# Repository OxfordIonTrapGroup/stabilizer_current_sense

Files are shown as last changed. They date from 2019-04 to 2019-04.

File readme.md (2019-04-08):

Analogue front-end mezzanine for [Stabilizer](https://github.com/sinara-hw/stabilizer), providing current sense (with reference subtraction) and modulation (feedback + feedforward). Originally designed to reduce magnetic field noise in AMO physics experiments. See [Merkel et al.](https://arxiv.org/abs/1808.03310) for details.

Pre-build schematics, gerbers etc are avaliable in the [releases](https://github.com/OxfordIonTrapGroup/stabilizer_current_sense/releases) section. [sim.ipynb](https://github.com/OxfordIonTrapGroup/stabilizer_current_sense/blob/master/sim.ipynb) contains design notes, noise simulations, etc

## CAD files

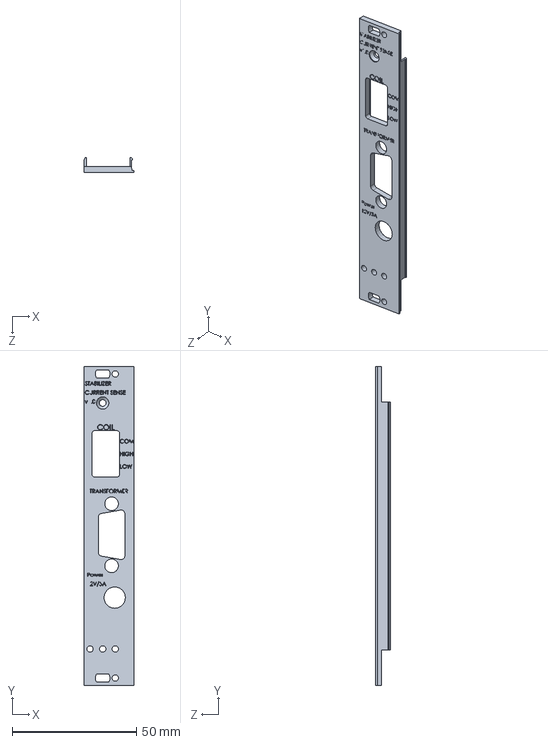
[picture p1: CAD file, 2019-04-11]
panel/panel.SLDPRT
20.0 x 128.4 x 6.20 mm

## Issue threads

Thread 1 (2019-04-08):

board-board connector heights

hartytp, 2019-04-08:
The -33 connectors are too long given the male connectors used in Stabilizer. The -23 connectors I've used look a bit marginal. See the STEP exports for a clearer picture.

Consider adding a spacer to increase the contact area between the male connectors on Stabilizer and the female ones on the AFE?

hartytp, 2019-04-08:
Well, probably not a spacer but rather a note that the AFE connectors should be soldered approx 1mm away from the PCB to increase the length.

hartytp, 2019-04-08:
Looking at the connector models more closely I think this will be fine; the connectors are sprung so that contact is only at the tips so not much insertion should be needed for proper contact. Still to be safe I’ll leave the connectors off the initial BOM and solder them be hand once I’ve test-fitted.

Closed 2019-04-12.

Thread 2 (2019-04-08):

1v.0 rc1 design review

hartytp, 2019-04-08:
@gkasprow I've just posted a first version of the design, would you mind taking a look?

The only obvious issue I see is #1

Note that I've put quite a lot of thought into the grounding, since we need to measure <1uV voltages across the sense resistor. In a previous version we had some nasty issues like: an LED that flashed at ~1Hz and we could see a corresponding signal on the current measurement; the current sunk by the shunts created a ground voltage that altered the current measurement. These were all fixed with grounding, but it took some care!

Other than that, it would be great if you could have a look at the usuals (schematic, layout, mechanics) and, since I'm new to Altium, do let me know if you see anything silly with the way I've set the Altium project up.

Otherwise, I'll order some of these boards in the next few days. Is one enough for you?

hartytp, 2019-04-09:
Now on rc2.

Main change is that when I added a mating connector for the terminal block I noticed that the locking terminal blocks wouldn't fit. Fixed the component placements and panels to allow use of locking terminal blocks.

NB we won't be able to use one of the fancy Schroff panels with EMC gaskets unless we trim the pins on the terminal block. But, the same goes for the SMAs on Stabilizer AFAICT.

Other than that, the mechanics looks good apart from #1.

gkasprow, 2019-04-10:
@hartytp
- trimming pins is the usual procedure.
- there are missing decoupling caps on IC11 and IC10 supplies
- move all 3D models to layer 13
- missing board outline on mechanical 1. This is needed for PCB milling.
- mask vias, don't treat them as test points because can be easily damaged with a probe

gkasprow, 2019-04-10:
edit, the decoupling caps are there, on other sheet :)

gkasprow, 2019-04-10:
What is D1 for? Wouldn't it be better to use it in the feedback loop to close it for negative inputs?

hartytp, 2019-04-10:
> trimming pins is the usual procedure

ack. Is that something that you specify somewhere on the PCB? Or just leave to the assembly house to figure out?

> there are missing decoupling caps on IC11 and IC10 supplies
> edit, the decoupling caps are there, on other sheet :)

Nope, they're there on the same sheet. C34-C36

> move all 3D models to layer 13

Done

> missing board outline on mechanical 1. This is needed for PCB milling.

Okay, I'll add that.

> mask vias, don't treat them as test points because can be easily damaged with a probe

Done. Thanks

hartytp, 2019-04-10:
> What is D1 for? Wouldn't it be better to use it in the feedback loop to close it for negative inputs?

May not be necessary. The idea is to protect the transitor's base from negative voltages when the feedback loop rails low.

gkasprow, 2019-04-10:
the air flow cooling the output transistors can be blocked by the DC/DC converter. I don't know how hot they are going to be.
Trimming of the pins will be done during panel assembly so the assembly house will figure it out

hartytp, 2019-04-10:
> the air flow cooling the output transistors can be blocked by the DC/DC converter. I don't know how hot they are going to be.

Imax is about 0.1A. The power depends on the coil voltage. Assume a max coil voltage of something like 10V (which is pretty high) the max power will be 1 W. The [heatsink](https://www.fischerelektronik.de/web_fischer/en_GB/heatsinks/C02/Attachable%20heatsink/PG/FK242SA220O/search.xhtml) specifies 26K/W thermal resistance, but not sure what air flow that assumes. Either way, the transistors shouldn't get too hot, maybe 50C or so.

I'm assuming we'll mount the circuit virtically in an enclosure with some vent holes on the top.

gkasprow, 2019-04-10:
When making cuts via power planes, make sure they are not shorted on other layers for AC.
At the moment the cutout is shorted by R50. The N15 plane is also placed across the cutout.

gkasprow, 2019-04-10:
the EMI filter should be placed as close to the connector as possible. When placed somewhere else its effectiveness gets degraded, especially for higher frequencies. it would fit nicely on the bottom side, close to the connector.

gkasprow, 2019-04-10:
watch the via sizes on power rails. I add a dedicated rule and make sure all power rails are added to the power class.
Use two or three vias in parallel. If Altium is removing them, add piece of copper fill to connect them together (p-f command). At the moment the pin 1 of EMI filter is connected  to the power connector witn big via which has 0.5mm hole

gkasprow, 2019-04-10:
Wouldn't make it better to place RN1 on the bottom side? The feedback traces seem to be quite long.
I don't care on signal integrity but interference pickup.

gkasprow, 2019-04-10:
Good idea with adding panels to the BOM!

gkasprow, 2019-04-10:
are you sure the connectors you used are good for such stacking? On the 3D view it looks like the header may have too short pins to ensure reliable contact. It depends on how the receptacles are built - if they have an active contact surface close to the pin entry or at some depth.

hartytp, 2019-04-10:
Thanks Greg. Let me know when you've finished your review.

gkasprow, 2019-04-10:
I didn't found any other issues.

hartytp, 2019-04-10:
Thanks @gkasprow!

hartytp, 2019-04-10:
> move all 3D models to layer 13

So, here you mean J7 as well as the screws, washers and stand-offs, right? I think everything else was already on the correct layer.

For stand-off/alignment purposes, is mechanical 1 the same as top layer?

hartytp, 2019-04-10:
> missing board outline on mechanical 1. This is needed for PCB milling.

@gkasprow is there an easy way to have altium copy the board outline on to m1 or do I need to manually trace it using zero-thickness lines?

hartytp, 2019-04-10:
> When making cuts via power planes, make sure they are not shorted on other layers for AC.
At the moment the cutout is shorted by R50.

R50 and other similar resistors are DNP by default. They are deliberately placed there to short across the isolation gap if we decide we want to tie all grounds together at some point. There is a schematic annotation about this.

> The N15 plane is also placed across the cutout.

Several power planes cut across the isolation gap. But, this is a requirement to bring the signals out. I don't think we can avoid it. I wasn't expecting this to be a problem, as the capacitance between the layers should be relatively small and the noise frequencies should be relatively low. Do you think this is really likely to be an issue? How would you alter the layout to improve it?

> the EMI filter should be placed as close to the connector as possible. When placed somewhere else its effectiveness gets degraded, especially for higher frequencies. it would fit nicely on the bottom side, close to the connector.

I did think about doing that. However, in this particular case, I deliberately chose not to do that. The reason is that the area near the barrel connector has my low-noise AFE ground, so I do not want to ground the CMC there. I want to ground the CMC in the "noisy" region near the main SMPS.

I know this will degrade the CMC performance somewhat for high frequenices, but my assumption was that the bulk of the noise we want to filter out is <1MHz so the coupling between the power input traces and the surrounding ground planes should be very small.

What do you think?

> watch the via sizes on power rails. I add a dedicated rule and make sure all power rails are added to the power class.
Use two or three vias in parallel. If Altium is removing them, add piece of copper fill to connect them together (p-f command). At the moment the pin 1 of EMI filter is connected to the power connector witn big via which has 0.5mm hole

> Wouldn't make it better to place RN1 on the bottom side? The feedback traces seem to be quite long.
I don't care on signal integrity but interference pickup.

Yes, I guess we can do that. I'm used to hand soldering PCBs so I like to keep all components on one side where possible :) It's also nice to keep all components on the same layer in case we want to add a screening around the low noise parts can or something later on. Also, the layout currently puts keeps all critical ground connections (the reference, the dividers, the DAC and the feedback resistors) very close together, which seemed nice.

In any case, the feedback traces are not so long (~15mm) and the subsequent stages have filtering.

So, all in all, I hoped the current layout would be fine. What do you think?

> Are you sure the connectors you used are good for such stacking? On the 3D view it looks like the header may have too short pins to ensure reliable contact. It depends on how the receptacles are built - if they have an active contact surface close to the pin entry or at some depth.

Yes...this is https://github.com/OxfordIonTrapGroup/stabilizer_current_sense/issues/1 I think it may be an issue.

Let's discuss the problem in that thread. Briefly though:
- there is no connector that I could find which is a closer match for our stack up. The longer connectors are about 1mm too long to mate with the headers on Stabilizer.
- one possibility would be to solder the connectors slightly below the AFE PCB to increase the mating lenght. e.g. we can solder them in situ with the board mounted on Stabilizer, or we can add a 1mm spacer before soldering.
- From the connector models in the step file, it looks like the female connectors are sprun-loaded with a contact point right at the tip, so this may not be an issue in the end. But, it's hard to be confident until we play with the hw...

gkasprow, 2019-04-10:
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

OK
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

I would simply make some supply rails longer that go around the slot. Look how it was made on Sampler.

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

you can ground it in another place. At the moment the input traces are capacitively coupled with your AFE ground.

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

probably does not really mater at such low frequencies we are working.

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

that is fine, I'm talking only on general engineering rules :)

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

this needs to be communicated to the assembly house. They will use standoffs to mount the connector in elevated way.

>     From the connector models in the step file, it looks like the female connectors are sprun-loaded with a contact point right at the tip, so this may not be an issue in the end. But, it's hard to be confident until we play with the hw...
>

this should not be an issue then.

hartytp, 2019-04-11:
@gkasprow for power planes, what via hole and annuls size do you recommend? How many in parallel for a few hundred mA?

gkasprow, 2019-04-11:
0.4/0.7mm, 2 in parallel.

Closed 2019-04-11.

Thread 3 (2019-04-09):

box

cjbe, 2019-04-09:
@gkasprow can you recommend any compact stand-alone cases which we could mount Stabilizer + mezzanine in using standard Schroff FPs?

gkasprow, 2019-04-10:
U can use [these](https://www.parkfield.co.uk/verotec_us/lbx-tac-print.jpg) or [these](http://www.farnell.com/datasheets/48895.pdf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)
The later one I have in my lab.

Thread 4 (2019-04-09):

box grounding

hartytp, 2019-04-09:
I'll make a final decision on this later on and then add some notes/alter population options in the schematic. But, my provisional grounding plan is:
1. We float the stabilizer front panel so that it connects electrically to the box but not to stabilizer
2. We connect the AFE panel to the AFE board in exactly 1 place using the DNPd resistor right by the main star ground point
3. We connect the AFE panel to the chassis electrically
4. We tie either COIL_COMMON or the chassis to the optics table

That way we get a nice star ground with no loops...

hartytp, 2019-04-11:
Here is what we will do:
1. Stabilizer connects its circuit ground to the panel ground in several places (can't avoid that)
2. Connect both stabilizer and AFE grounds to the chassis (e.g. star washers on case)
3. Then either ground the chassis, or ground coil common

Closed 2019-04-11.

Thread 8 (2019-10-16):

v1.0 testing

hartytp, 2019-10-16:
- [ ] measure all voltage rails and check within spec. Check with scope that nothing oscillating etc
- [ ] program SPI AFE DAC and verify output
- [ ] short current input and measure noise spectrum (if we can't do this because of offsets, we can use a battery + precision resistor to produce a small bias current with very low noise)
- [ ] Compare noise measurements to simulations in notebook
- [ ] Get stabilizer CPU DAC working to bias current shunts
- [ ] test current shunts by hooking up to external current source and putting a square-wave on the stabilizer SPI DAC. Look at sense resistor on scope to measure step response
- [ ] try running closed-loop

pathfinder49, 2019-10-16:
| V Rail    | Voltage (DMM) |
|------------|---------------------|
| P15V0   | 15.12 V |
| N15V0   | -14.96 V |
| P12V0A | 12.01 V |
| N12V0A | -12.05 V |
| 12V0AS | 12.29 V |
| VREF    | 2.500 V |
| P5V0    | 4.971 V |

Verified on a scope that the rails aren't oscillating.

hartytp, 2019-10-16:
Are those all within spec for the PCB?

pathfinder49, 2019-10-16:
>
>
> Are those all within spec for the PCB?

Those are all within spec of the connected components. I can't seem to find a tolerance within the PDF.

hartytp, 2019-10-16:
> Those are all within spec of the connected components

That's all I meant; cast an eye over the PCB, dig out the ICs and see what accuracy you expect from that.

pathfinder49, 2019-10-28:
Below are the stabilizer ADC readings when connected to stabilizer_current_sense. (I've plotted every 100th point)

`np.diff(data).std()/2**.5` = 10.8 LSB or 1.3 mV

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

pathfinder49, 2019-10-28:
With R33 and R34 populated and Coil COM and Coil LOW shorted.

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

There is a significant voltage offset with this configuration. See [new issue](https://github.com/OxfordIonTrapGroup/stabilizer_current_sense/issues/9).

pathfinder49, 2019-10-28:
The voltage fluctuations appear to originate from a [broken capacitor in the DAC filter](https://github.com/OxfordIonTrapGroup/stabilizer_current_sense/issues/10).

Using a different current_sense_board:
`np.diff(data).std()/2**.5` = 10.8 LSB or 1.3 mV (no significant change to previous board)
(6.2 mV RMS noise on scope)
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

hartytp, 2019-10-28:
@pathfinder49 can you fft that to extract the nsd and compare it to the simulation please? Looks about right but would be nice to see the nsd plot

hartytp, 2019-10-28:
@pathfinder49 are you saying the ADC reads 1.3mVrms but the scope gives 6.4?

pathfinder49, 2019-10-28:
Yes, I'll double check my conversion once I've eaten. Might have /2 instead of x2...

pathfinder49, 2019-10-28:
I believe my conversion is correct. The `np.diff(data).std()/2**.5` disagrees with the rms of the ADC data (2.4 mV). However, this RMS also disagrees with the scope...

Below is the NSD of the ADC data (assuming 1 MHz sampling TBC):
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

hartytp, 2019-10-28:
I'm confused. Why are you differentiating the data?

hartytp, 2019-10-28:
Where does `np.diff(data).std()/2**.5` come from? Don't just just want `np.std`?

hartytp, 2019-10-28:
Pretty sure sampler currently samples at 500kHz (try injecting a 1kHz sinusoid from an AWG to confirm).

pathfinder49, 2019-10-28:
For a comparison of the no capacitor related noise

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

hartytp, 2019-10-28:
> For a comparison of the no capacitor related noise

Okay...but I don't get where that formula came from in the first place...

hartytp, 2019-10-28:
nit: always use grids for that kind of plot, and may be best to give y scale as a log (dBV/sqrt(Hz))

hartytp, 2019-10-28:
- did you add a 10nF capacitor in place of the 10uF yet? Or is this all no capacitor?
- is the NSD you're plotting there RTI (i.e. divided by the gain)?

hartytp, 2019-10-28:
I don't understand the data on the plot. AFAICT it says 1uV/rtHz for 500kHz BW. That would be 1.4nV/rtHz. Even if that's RTI it's non-physically low (1kOhm is 4nV/rtHz at room temperature and we have a bunch of 1k resistors. Check the noise model, but I'd guess the AFE noise floor is closer to 10nV/rtHz). So, check it in the AM, but I don't trust your data yet...

dnadlinger, 2019-10-28:
> I don't understand the data on the plot. AFAICT it says 1uV/rtHz for 500kHz BW.

Wait what? 1 µV / rtHz is 1 µV / rtHz no matter the bandwidth. For, order-of-magnitude 500 kHz noise bandwidth, this gives 0.7 mV rms, so factors of 2 might be wrong, but not factors of 1000.

hartytp, 2019-10-28:
@dnadlinger indeed...it’s late and my brain clearly no longer functions!

hartytp, 2019-10-28:
Still though 1uV/rtHz would be 0.5nVrtHz before gain of 2k, so still at least an order of magnitude too low.

pathfinder49, 2019-10-29:
It was suggested in the stabilizer characterisation

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

pathfinder49, 2019-10-29:
Working through the circuit diagram, I hadn't accounted for the op amp dividing input voltage by 5.

I've updated the nsd and voltage above.

hartytp, 2019-10-29:
> Working through the circuit diagram, I hadn't accounted for the op amp dividing input voltage by 5.

So, the calculation you need is that 2^16 is 20V at the input to Stabilizer (the header/SMA).

pathfinder49, 2019-10-29:
Here is the nsd after savgol filtering
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

Overall the NSD is better than expected from the noise calculation. [This may have to do with the bandwidth.](https://github.com/OxfordIonTrapGroup/stabilizer_current_sense/issues/12)

hartytp, 2019-10-29:
Thanks!

Assuming the spice model is correct, the 3dB bandwidth of the circuit should be ~75kHz. However, the plot doesn't really look consistent with that. Which is odd.

I assume that the large spike near DC is an artefact of the filter? It's probably worth plotting this kind of thing on a semi-log x scale (or at the very least using kHz as the scale).

Assuming the noise in the pass band is ~16uV/rtHz (eyeballing the plot), before the gain of 2k, that would be 8nV/rtHz, which is still non-physically low...

So, I'm not sure we need to spend more time on this right now, but things don't quite add up yet.

I think a good next step would be to use an AWG to inject a low amplitude sinusoid current pulse into the sense resistor and measure the transfer function through the circuit. That way we can confirm the BW of the various stages.

I think it would also be a good idea to hook it up to the FFT analyzer, which will give you a NSD unit plot. That way we can check your maths.

Anyway, I think this is getting out of the scope of the current investigation, so I suggest you leave it here for now and move on to Thermostat.

pathfinder49, 2019-10-29:
NOTE: my NSDs are a factor 2 smaller than they should be as I misunderstood the definition.

hartytp, 2019-10-30:
@pathfinder49 I uploaded a spice model of the AFE as I was curious to see how good my analytic treatment was. The simulated low frequency noise is approx 11.4nV/rtHz, with a 3dB cut-off around 55kHz. By eye, the bandwidth agrees well with your plot. After fixing that factor of two, you get something like 16nV/rtHz RTI noise, where as the model gives 11.4nV/rtHz. So the measured value is 40% higher. Which is a bit large, but noise measurements never agree too well.

NB the OpAmp noise typical in the data sheet is 2.8nV/rtHz, max is 4.5nV/rtHz, which is 60% difference. In practice I wouldn't expect the variance to be that bad, but I'm also not concerned with this level of discrepancy. So, all in all, it looks like the AFE works! Great!

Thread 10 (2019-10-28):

DAC-Filter-Capacitor causes large temp-co

pathfinder49, 2019-10-28:
C33 is causing ~50 mV fluctuations in V_err.
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
This measurement is when lying on a desk, undisturbed.

Covering the capacitor with tissue removes the fluctuations. De-soldering the capacitor gives a steady V_err with noise consistent with the unfiltered DAC.

For the de-soldered capacitor:
RMS noise = 8.4 mV
200 kHz pole in V_offset addition
2000x gain to v_err
=> 9 nV/sqrt(Hz) noise
From DAC data-sheet: 11.8 nV/sqrt(Hz)

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

cjbe, 2019-10-28:
Good find! What is the plan to fix this - replace it with an electrolytic?

pathfinder49, 2019-10-28:
The Previous measurement was with the boar:
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

Using another board:
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

The behavior is NOT observed. The output is stable with 6 mV RMS noise. Touching the capacitor still causes causes large voltage spikes of over 1 V.

pathfinder49, 2019-10-28:
> Good find! What is the plan to fix this - replace it with an electrolytic?

Seems to be the case of a broken capacitor?

hartytp, 2019-10-28:
I don’t know what to do here. Let’s gather statistics with the other boards before making a decision. Maybe it was a broken cap (I don’t understand the physics behind such a large thermal emf otherwise)?

With electros I’d worry about the leakage temp co as the dac has a high z output. Could consider reducing the cap size and going for a large plastic?

dnadlinger, 2019-10-28:
We could always add a second buffer stage and use the leakage-free parallel RC technique (i.e. keep zero volts across one capacitor up to R matching, which can then be leaky).

dnadlinger, 2019-10-28:
It really seems like this shouldn't be that big an effect, though.

hartytp, 2019-10-30:
Let's assume it was a broken cap. We'll gather more statistics for looking at other boards, and only worry if the issue surfaces on a new board...

Closed 2019-10-30.

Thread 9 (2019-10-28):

Feed-Forwads: crosswired op-amp

pathfinder49, 2019-10-28:
The feed-forwads-loop feed-back has a sign error. This causes IC8 to rail at +12V.

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

The feed back sign can be corrected by cross wiring R29 and R31.
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

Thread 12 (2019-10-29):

error amplifier BW

hartytp, 2019-10-29:
Probably not an issue, but the first stage amp bw is quite a bit lower than intended. OpAmp input capacitance? IIRC some feedback capacitance is needed to keep the OpAmp stable with a large feedback resistor, but the capacitor we currently have gives a 3dB point (according to LTSPice) of approx 75kHz.

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

To do (if anyone can be bothered) play with the simulation and do a transfer function/noise analysis and find a capacitor value that gives approx the BW we want without excessive ringing.

@pathfinder49 this probably explains why the RMS noise we measure is a little lower than we expect. `6.4mV/sqrt(1.57*75kHz)/2000=9nV/rtHz` which is pretty close to the model. To get better agreement than that, we'd have to step through the circuit carefully, checking bandwidths and gains at various stages, but I'm pretty happy that there is nothing grossly wrong and everything seems to work as expected so far, which is good!

Closed 2019-10-30.

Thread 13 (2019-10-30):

Add simulation outputs to schematic

hartytp, 2019-10-30:
From the spice model:

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

Low frequency output noise is 11.4nV/rtHz RTI. 3dB noise bandwidth is approx 55kHz.

hartytp, 2019-10-30:
Gain and phase for a current source input

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

hartytp, 2019-10-30:
3dB bandwidth is 45kHz, 6dB BW is approx 70kHz

hartytp, 2019-10-30:
At 1kHz, our phase margin is 178deg (2 deg of phase lost). So, that's fine for the typical loops we use. No high frequency gain/noise peaking evident.

Good!

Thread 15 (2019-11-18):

FEEDBACK_OFFSET transconductance gain annotation

dnadlinger, 2019-11-18:
According to the schematic, the transconductance from FEEDBACK_OFFSET to the feedback shunt current is 47 mA / V, but it looks like it should be 23.5 mA / V, giving a total range of 0 mA to 48 mA.

dnadlinger, 2019-11-18:
I checked the rest of the gain calculations as well, and they are correct (divider ratios are slightly off).

hartytp, 2019-11-20:
Thanks!

hartytp, 2019-11-20:
I suspect I changed the sense resistor at some point and forgot to update the annotation.

Closed 2019-11-20.

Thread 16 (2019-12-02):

Increase feed-forward current sink compensation capacitor

dnadlinger, 2019-12-02:
The loop compensation capacitor for the feedforward current sink, C24, isn't large enough to prevent oscillations even under fairly benign load conditions (TTI single-channel PSU, 10Ω wire-wound resistor in place of coils). Increasing it to 100 pF solves the issue, and still leaves tons of bandwidth headroom compared to the FF input pole.

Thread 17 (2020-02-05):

Non-C0G capacitor in frontend offset filter

DougalMain, 2020-02-05:
It's been noticed that the non-C0G capacitor (C33) in the frontend offset filter is very sensitive to thermal fluctuations. This leads to fluctuation of the feedback setpoint and thus causes large, low frequency drifts in the coil supply current.

To characterise this the open loop noise was measured for two (seperate) stabilizers, one with the old non-C0G capacitor and one with a plastic foil capacitor of equal capacitance (10uF).

Blue - with original capacitor
Orange - with replacement capacitor

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

While there are other non-C0G capacitors in the circuit, C33 has by far the largest effect. Should either reduce the capacitance of C33 so that a C0G capacitor can be used or find another alternative.

dtcallcock, 2020-02-06:
I've used these reflow-compatible SMT film caps in designs like this where they don't make C0G big enough.  Only downside is that they are $$$ and about 4x the size of an X5R.

https://www.digikey.com/product-detail/en/rubycon/35MU106MD35750/1189-2530-1-ND/4969588

dnadlinger, 2020-02-08:
Thanks for the tip – spendy! We'll probably rejig this part of the circuit instead to use the "bootstrapped" RC filter trick (where 0V is across the top capacitor, which can then have leakage, courtesy of a duplicate RC), although we'll have to add an op-amp buffer after the DAC.

dtcallcock, 2020-02-09:
> We'll probably rejig this part of the circuit instead to use the "bootstrapped" RC filter trick (where 0V is across the top capacitor, which can then have leakage, courtesy of a duplicate RC), although we'll have to add an op-amp buffer after the DAC.

Out of interest, is there an advantage to this other than saving a few $?  Seems it increases complexity, noise, board area, and power consumption.  Admittedly none of them by much.

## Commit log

2019-04-08 add altium files
    [current_frontend.SchDoc, current_shunts.SchDoc, current_stabilizer.PrjPCB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]
2019-04-08 move altium files to sub dir
    [current_frontend.SchDoc, current_shunts.SchDoc, current_stabilizer.PrjPCB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]
2019-04-08 move missing altium file to sub dir
    [mechanics.SchDoc]
2019-04-08 add panel
    [panel.SLDPRT]
2019-04-09 update panel after fixing mechanics
    [panel.SLDPRT]
2019-04-09 update altium files after: generate gerber files, add mating terminal block connector to design, fix mechanics around terminal block
    [current_frontend.SchDoc, current_shunts.SchDoc, current_stabilizer.PrjPCB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]
2019-04-11 updates after rc2 design review - move all 3d models to layer m1 - add board outline to m1 - tent vias - minimize places where planes cross isolation gaps - move power input cmc to right by connector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
    [current_stabilizer.PrjPCB, current_stabilizer.SchDoc, mechanics.SchDoc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]
2019-04-12 a few final modifications before sending to production: tweak via sizes on power traces; fix m1 layer
    [current_stabilizer.PrjPCB, mechanics.SchDoc]
2019-04-12 bump revision on schematic
    [current_stabilizer.PrjPCB]
2019-04-13 add fids, start tidying up file names
    [frontend.SchDoc, shunts.SchDoc, stabilizer_current_sense.SchDoc]
2019-04-13 finish renaming files
    [current_stabilizer.PrjPCB, stabilizer_current_sense.PrjPCB]
2019-04-13 fix file names for output files
    [stabilizer_current_sense.PrjPCB]
2019-11-20 Schematic: Fix/clarify current sink annotations
    No electrical changes (intended); just fixed the feedback
    offset range annotation and clarified things a bit.
    GitHub: Fixes #15.
    [shunts.SchDoc]
